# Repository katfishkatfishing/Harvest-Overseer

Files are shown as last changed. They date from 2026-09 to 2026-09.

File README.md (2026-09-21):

# Harvest-Overseer 🌱
>Built for third space Hack Club! - Week 1️⃣  
_It all started when two unemployed dudes stumbled upon a third, equally unemployed dude. Unburdened by 9-to-5s (erm but we have 9-5s for school) and fuelled by sheer ambition, the trio set off to blaze new trails, conquering land, sea, and hardware. Day and night they grind towards their goal — will they pull it off? Only fate can tell._

A stationary, comprehensive agricultural monitor that measures soil pH, moisture levels, nutrient concentrations (NPK), and light intensity. It displays the data of the plant and soil's health on an OLED screen to let you easily know what your plant needs.

## 💠 Project Overview 💠
**Harvest-Overseer** is an all-in-one agricultural monitor designed to take the guesswork out of plant care. Stationed directly in your garden bed or potted plant, it will continuously track essential environmental and soil parameters — displaying real-time health diagnostics on an integrated OLED screen so you always know exactly what your plants need to thrive.

### Key Features 🗝️
🥖**Soil pH & Nutrients Tracking:** Monitors pH balance and NPK (_Nitrogen, Phosphorus, Potassium_) concentrations.\
💧**Moisture Detection:** Measures active soil hydration levels to prevent over or under-watering.\
☀️**Light Intensity:** Tracks daily ambient light exposures to ensure optimal photosynthesis conditions.\
👁️**One-Glance Display:** Instant visual updates through a 7-pin SPI lcd.\
🔋**Battery Powered:** Fully portable design powered by a rechargeable Li-ion battery with integrated power management.  

## 🍰 PCB & Hardware Architecture 🥯
Harvest-Overseer uses a modular architecture consisting of a central **Master Unit (Main Brain)** for processing and display, and one or more remote **Sensor Node(s)** designed for low-power battery operation.
### Master Unit — The Core 🍎
The Master Unit receives sensor data, handles system logic, and drives the local OLED status display.
+ <ins>The BRAIN</ins>🧠 `ESP32-S3-WROOM-1-N16R8` to handle calculations, sensor input processing, and screen rendering.
+ <ins>The FACE</ins>🥶 14-pin socket (Conn_01x14_Socket) featuring dedicated connections for a `7-Pin SPI lcd` (_GND, VCC, CLK, MOSI, RES, DC, CS_)
+ <ins>The HEART</ins>🫀 An  integrated footprint of `TP4056充电源模块板` or `TP4056 charging power module board` for safe USB-C power delivery and Li-ion battery charging, and a `TPS7133Q` (a low dropout voltage regulator) that converts 4.2V to 3.3V for a clean and stable voltage rail for the ESP32-S3 and other sensitive logic pins.

_Master Unit PCB and Schematics_
<table>
  <tr>
    <td align="center">
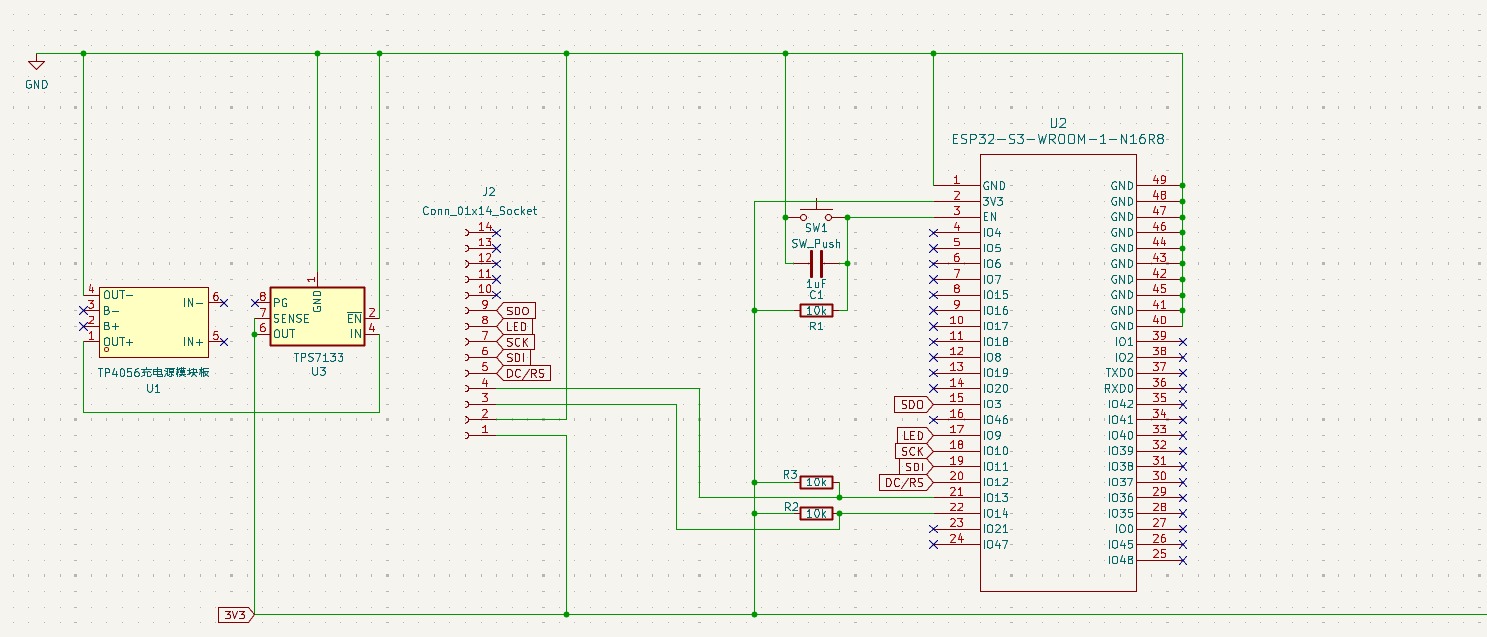
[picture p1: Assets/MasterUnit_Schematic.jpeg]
Master Unit Schematic
      <br>
      Schematic
    </td>
    <td align="center">
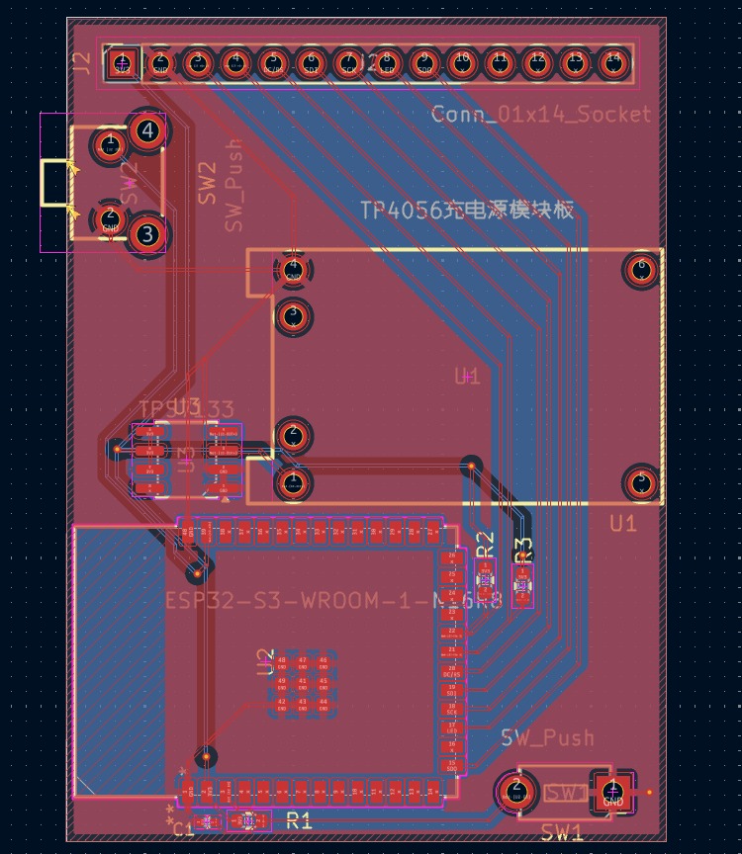
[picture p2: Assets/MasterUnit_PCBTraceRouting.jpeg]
Master Unit PCB Trace Routing
      <br>
      PCB Trace Routing
    </td>
  </tr>
  <tr>
    <td align="center">
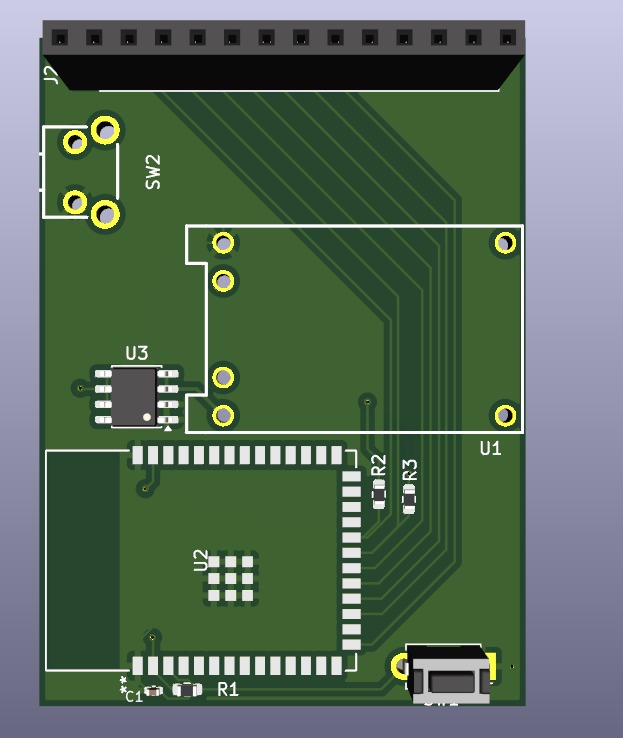
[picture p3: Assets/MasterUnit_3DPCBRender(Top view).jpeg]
Master Unit 3D PCB Render (Top view)
       <br>
      3D PCB Render (Top view)
    </td>
    <td align="center">
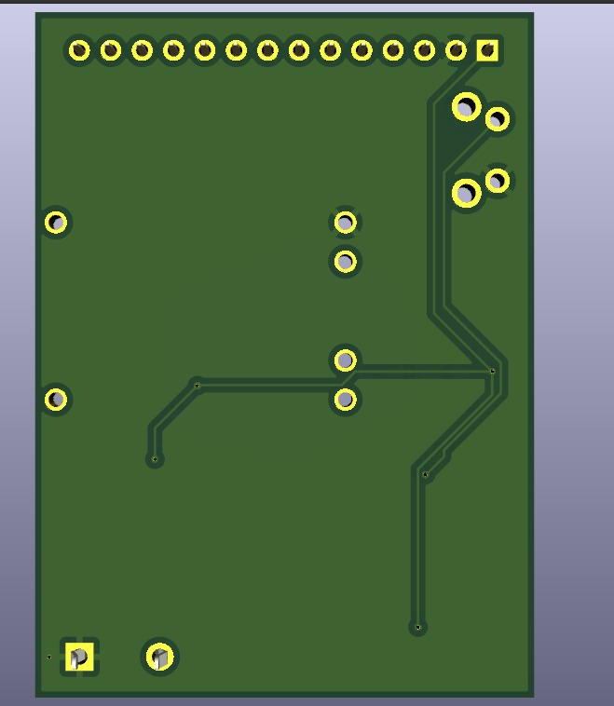
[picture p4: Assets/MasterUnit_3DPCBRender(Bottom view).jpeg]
Master Unit PCB Render (Bottom view)
      <br>
      3D PCB Render (Bottom view)
    </td>
  </tr>
</table>

### Sensor Node — The Backbone 🐙
The Sensor Node is an autonomous, ultra-low-power unit stationed in the soil bed to read the pH, moisture, light, and NPK levels, transmitting readings wirelessly back to the Core.

#### Components & Silicon 💎
+ <ins>The BRAIN_1</ins> `ESP32-C3-WROOM-02` (compact RISC-V Wi-Fi/BLE MCU) for reading sensors and beaming data to the Main Brain.
+ <ins>Power Management</ins> `MCP73871-2CC`, a LiPo/Li-ion charge manager with automatic power path management, allowing simultaneous solar/USB power supply and battery charging.
+ <ins>A Timer</ins>⏲️ `TPL5110`, a nano-power system timer that completely cuts off power to the entire node until a scheduled wake interval, drastically reducing standby drain to nano-amps for a long-term outdoor work.
+ <ins>Another High-Efficiency Power Management Component</ins>, the `DMG3415U` (P-Channel MOSFET) used to physically power down high-draw soil sensors when the node is sleeping.
+ <ins>Voltage Regulation (LDO)</ins> `HT7333` (Low quiescent current 3.3V regulator for logic and sensor rails).

#### Connectors & Peripherals 🖇️
+ <ins>USB-C Interface</ins>🔋 a `USB4085` GCT 16-pin USB-C receptacle for charging and power delivery.
+ <ins>Sensor Terminal Blocks</ins> `WAGO 233 Series` tool-less spring-cage terminals (2x08 and 2x04) for wiring of soil sensors (pH, NPK, moisture, light).
+ <ins>User Controls</ins>🫳 `B3U-1000P` tactile push button for manual settings, `LED_SMD_0603` status LED for charging state, `68k,10k,2k,100k,5.1k resistor smd 0603 & 470R resistor smd 0402` and `10uF capacitor smd 0402`for signal conditioning, and power rail decoupling.

<table>
  <tr>
    <td align="center">
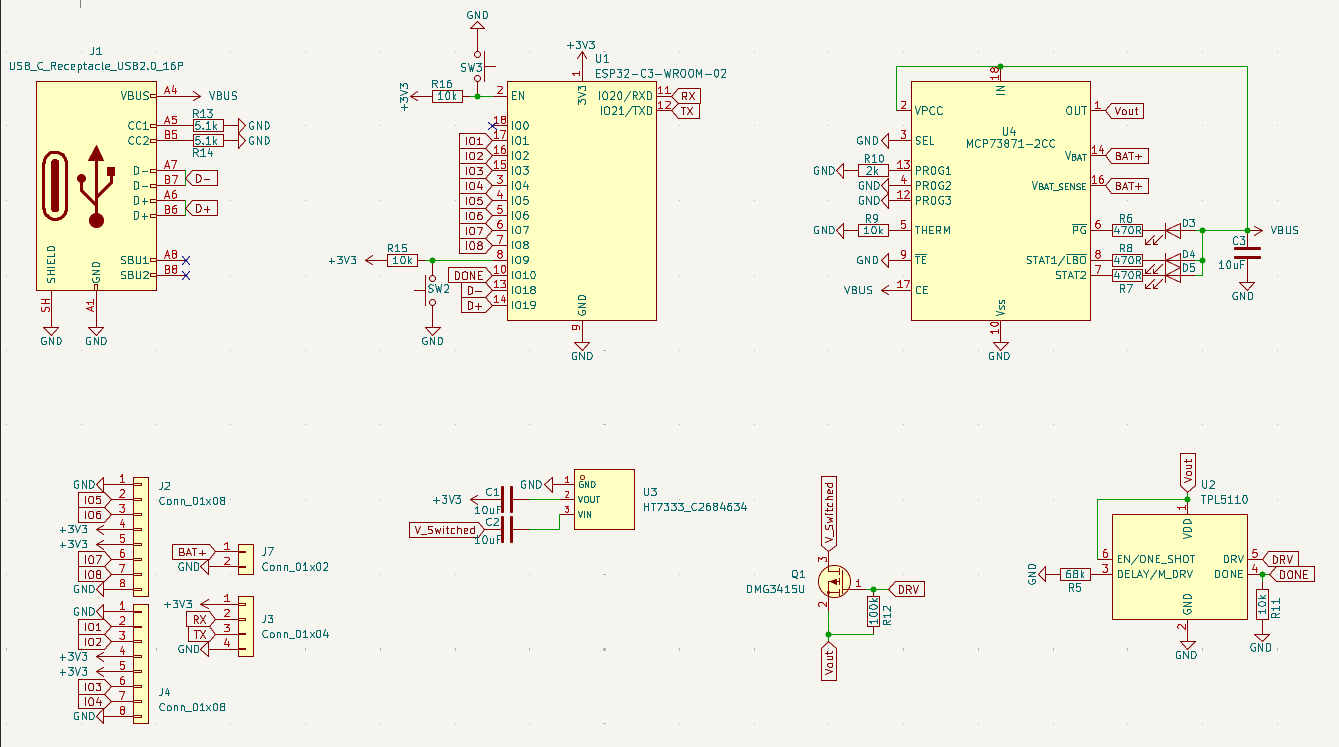
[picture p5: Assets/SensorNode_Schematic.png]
Sensor Node Schematic
      <br>
      Schematic
    </td>
  </tr>
</table>
<table>
  <tr>
    <td align="center">
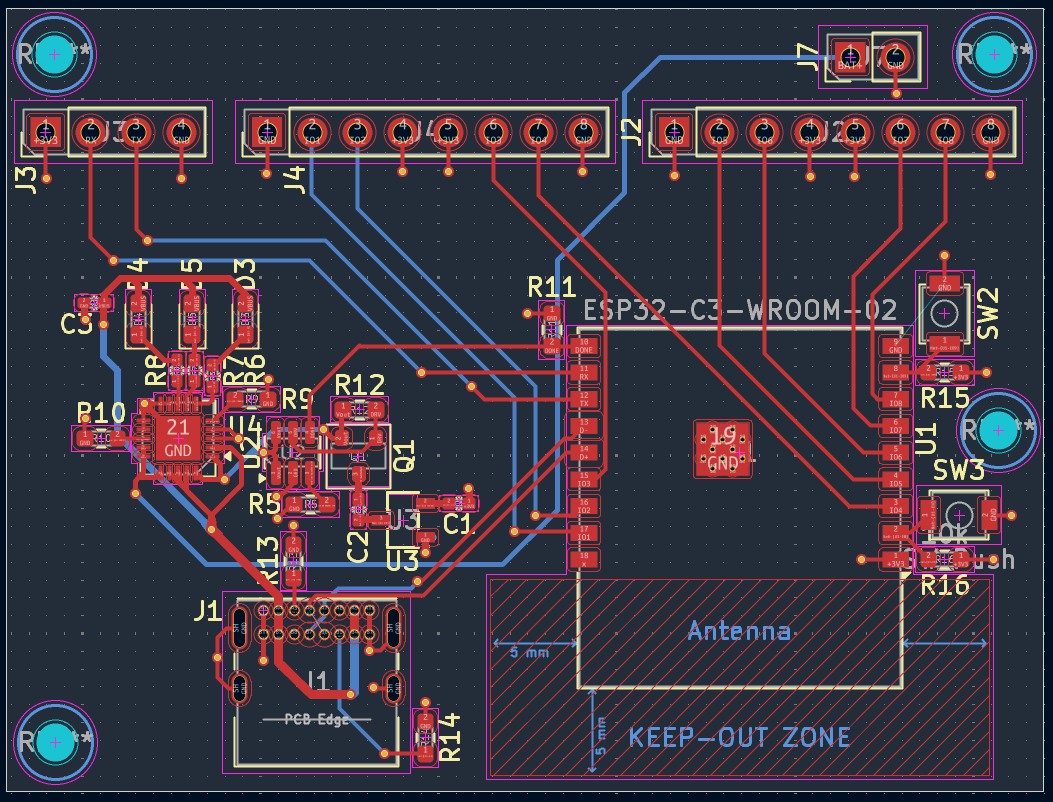
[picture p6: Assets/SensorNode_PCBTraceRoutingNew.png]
Sensor Node PCB Trace Routing
       <br>
      PCB Trace Routing
    </td>
    <td align="center">
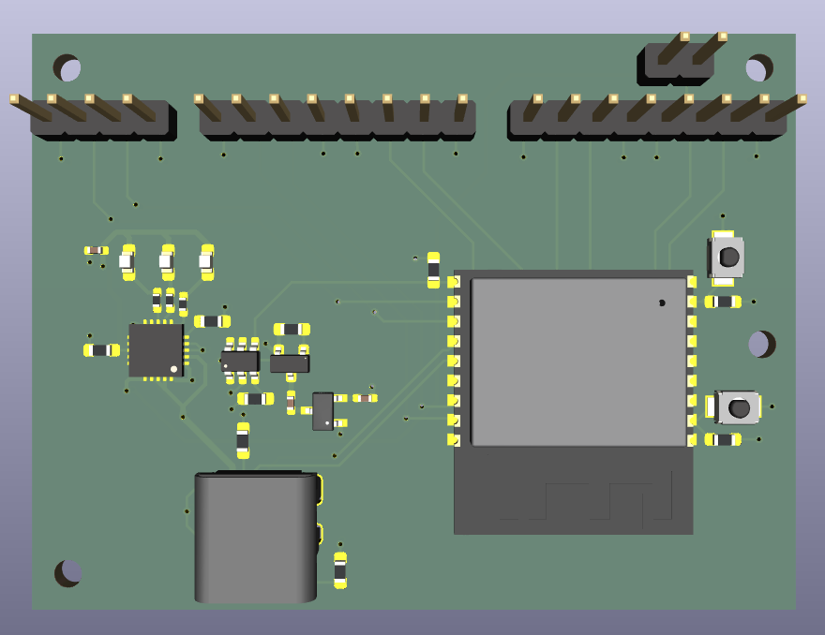
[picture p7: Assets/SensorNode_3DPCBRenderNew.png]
Sensor Node PCB Render
      <br>
      3D PCB Render
    </td>
  </tr>
</table>
<table>
  <tr>
    <td align="center">
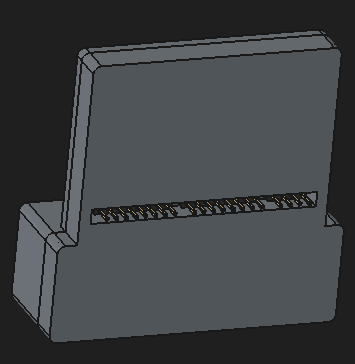
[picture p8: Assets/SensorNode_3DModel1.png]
Sensor Node 3D Model
       <br>
      3D Model
    </td>
    <td align="center">
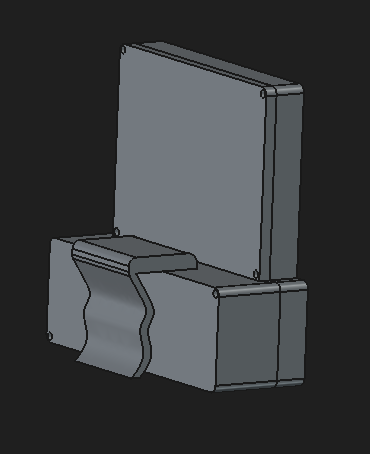
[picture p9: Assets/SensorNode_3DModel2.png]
Sensor Node PCB Render
      <br>
      3D Model
    </td>
  </tr>
</table>

## Display & User Interface 👾
`DLS24035B` for the display (3.5 Inch 480*320 SPI TFT LCD Module with ILI9488 Driver) with a custom case model.
<table>
  <tr>
    <td align="center">
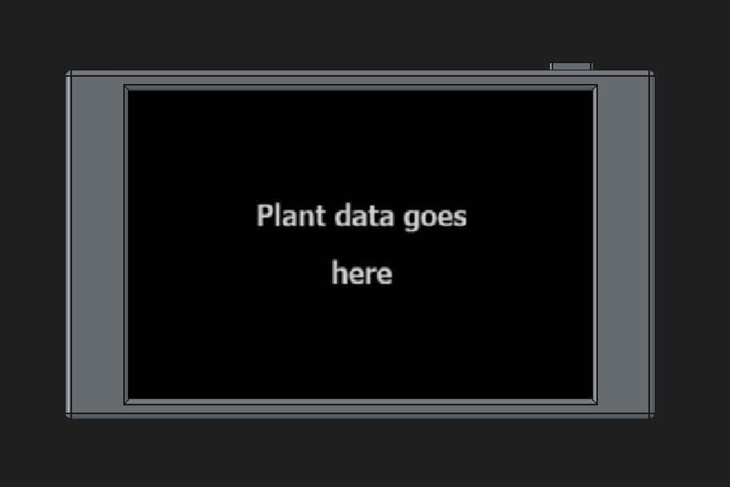
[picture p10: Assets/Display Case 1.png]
Angle 1
      <br>
      Front View
    </td>
    <td align="center">
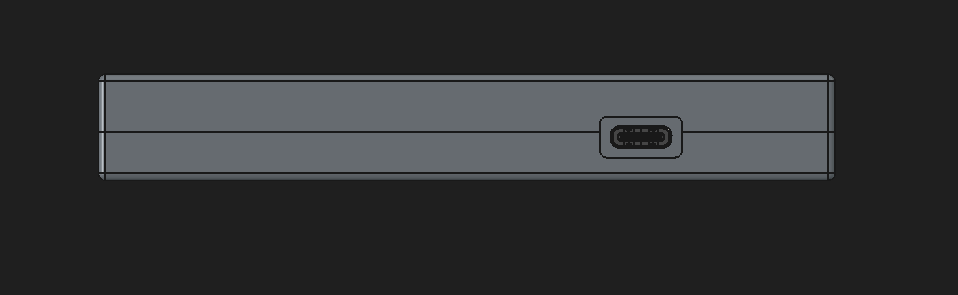
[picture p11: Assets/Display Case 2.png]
Angle 2
      <br>
      Bottom View
    </td>
  </tr>
</table>

_Here's a photo of the Master Unit PCB in the case._
<table>
  <tr>
    <td align="center">
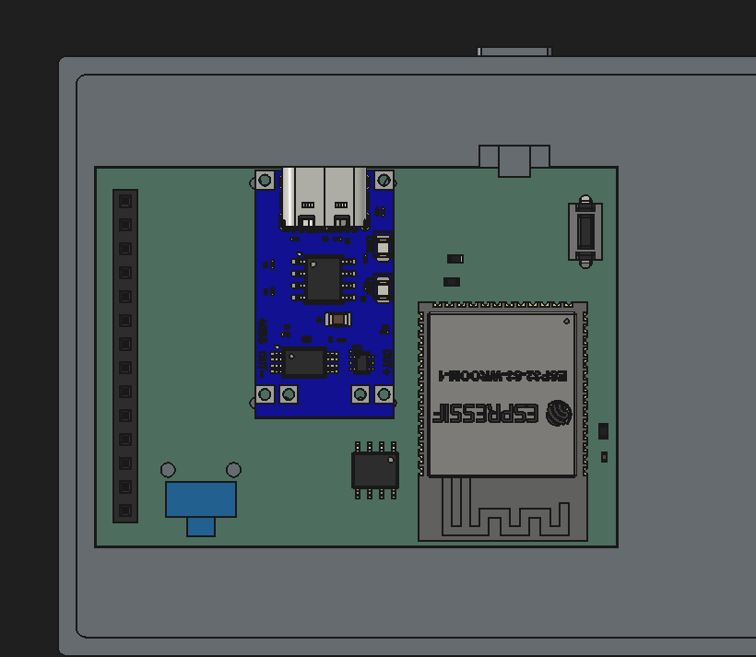
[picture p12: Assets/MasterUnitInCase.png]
3D PCB in case
      <br>
      Master Unit 3D PCB in case
    </td>
    <td align="center">
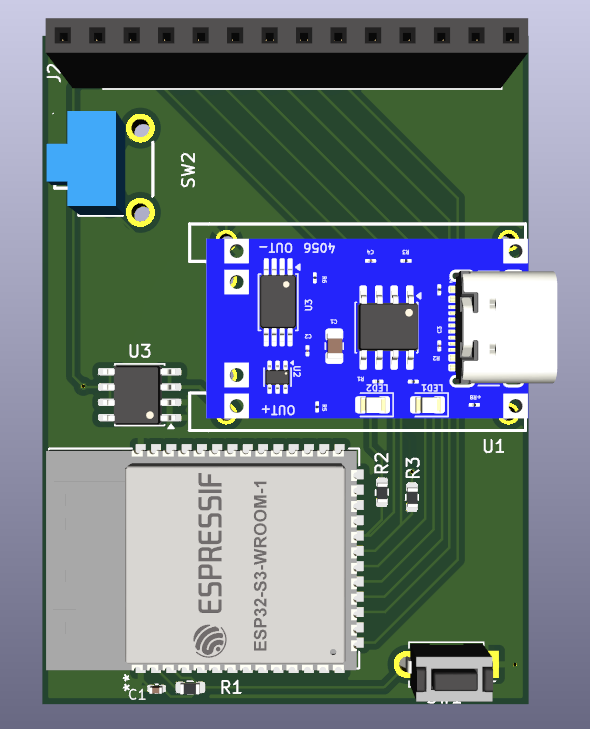
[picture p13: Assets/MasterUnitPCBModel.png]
3D PCB model
      <br>
      Master Unit 3D PCB model
    </td>
  </tr>
</table>

_Some display ui (done in the Figma software)_
<table>
  <tr>
    <td align="center">
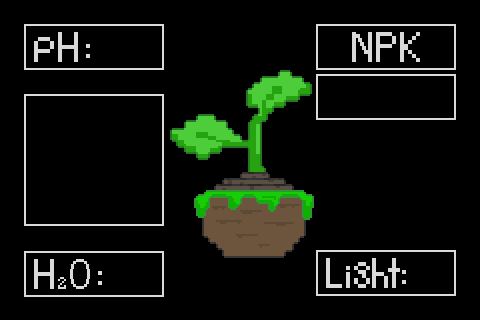
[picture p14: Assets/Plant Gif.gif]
Plant is helth
      <br>
      Plant in good helth
    </td>
    <td align="center">
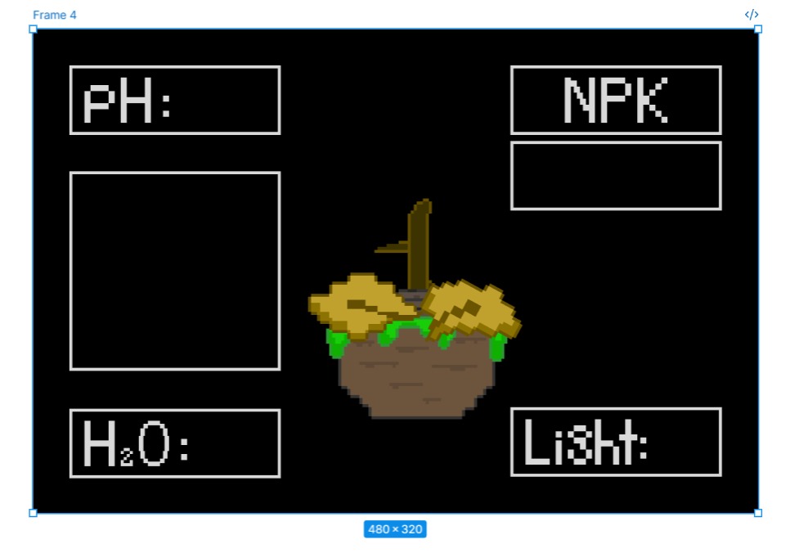
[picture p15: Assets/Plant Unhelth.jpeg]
Plant is unhelth
      <br>
      Plant is unhelth
    </td>
  </tr>
</table>

## Components Used
+ ESP32-S3-WROOM-1-N16N
+ 14-pin socket (Conn_01x14_Socket)
+ TP4056 charging power module board
+ TPS7133Q LDO
+ ESP32-C3-WROOM-02
+ MCP73871-2CC
+ TPL5110
+ DMG3415U
+ HT7333_C2684634
+ USB-C receptacle GCT_USB4085
+ Terminal block WAGO_233-508_2x08
+ Terminal block WAGO_233-508_2x04
+ Button switch SW_SPST_B3U-1000P
+ LED_SMD_0603
+ 10µF capacitor SMD 0402
+ 68k, 10k, 2k, 100k, 5.1k resistor SMD 0603
+ 470R resistor SMD 0402
+ DLS24035B (3.5inch 480*320 SPI TFT LCD Module with ILI9488 Driver)

## BOM
| MCU | ESP32-C3-WROOM-02 | 1 | 1.80  | 1.80  | https://www.aliexpress.com/item/1005003181553659.html |
| --- | --- | --- | ----- | ----- | --- |
| 2.54mm Female Header | Conn_01x08_Socket | 2 | 0.15  | 0.75  | https://www.aliexpress.com/w/wholesale-2.54mm-female-header.html |
| 2.54mm Female Header | Conn_01x04_Socket | 1 | 0.10  | 0.50  | https://www.aliexpress.com/w/wholesale-2.54mm-female-header.html |
| 2.54mm Female Header | Conn_01x02_Socket | 1 | 0.08  | 0.40  | https://www.aliexpress.com/w/wholesale-2.54mm-female-header.html |
| LiPo/Li-ion Battery Management IC | MCP73871-2CC | 1 | 2.20  | 2.20  | https://www.aliexpress.com/item/1005009931582723.html |
| Ultra-Low-Power Timer | TPL5110 | 1 | 3.50  | 3.50  | https://www.aliexpress.com/item/1005009324980307.html |
| P-Channel MOSFET | DMG3415U | 1 | 0.09  | 8.50  | https://www.aliexpress.com/item/1005009968198030.html |
| Low-Power LDO | HT7333_C2684634 | 1 | 0.10  | 1.00  | https://www.aliexpress.com/item/32697055615.html |
| USB-C Receptacle | GCT_USB4085 | 1 | 0.35  | 1.75  | https://www.aliexpress.com/w/wholesale-16p-usb-c-receptacle.html |
| Terminal block | WAGO_233-508_2x08 | 1 | 1.20  | 1.20  | https://www.aliexpress.com/w/wholesale-wago-233.html |
| Terminal block | WAGO_233-508_2x04 | 1 | 0.70  | 0.70  | https://www.aliexpress.com/w/wholesale-wago-233.html |
| Button switch | SW_SPST_B3U-1000P | 2 | 0.10  | 1.00  | https://www.aliexpress.com/w/wholesale-smd-tactile-switch.html |
| LED | SMD_0603 | 3 | 0.01  | 0.80  | https://www.aliexpress.com/w/wholesale-0603-smd-led.html |
| Ceramic Capacitor SMD | 10µF 0402 | 3 | 0.01  | 0.90  | https://www.aliexpress.com/w/wholesale-0402-10uf.html |
| Ceramic Resistor SMD | 68k 0603 | 1 | 0.01  | 0.50  | https://www.aliexpress.com/w/wholesale-smd-resistor-sample-book.html |
| Ceramic Resistor SMD | 10k 0603 | 4 | 0.01  | 0.50  | https://www.aliexpress.com/w/wholesale-smd-resistor-sample-book.html |
| Ceramic Resistor SMD | 2k 0603 | 1 | 0.01  | 0.50  | https://www.aliexpress.com/w/wholesale-smd-resistor-sample-book.html |
| Ceramic Resistor SMD | 100k 0603 | 1 | 0.01  | 0.50  | https://www.aliexpress.com/w/wholesale-smd-resistor-sample-book.html |
| Ceramic Resistor SMD | 5.1k 0603 | 2 | 0.01  | 0.50  | https://www.aliexpress.com/w/wholesale-smd-resistor-sample-book.html |
| Ceramic Resistor SMD | 470R 0402 | 3 | 0.01  | 0.50  | https://www.aliexpress.com/w/wholesale-smd-resistor-sample-book.html |
| Liquid Crystal Display | DLS24035B | 1 | 9.20  | 9.20  | https://www.aliexpress.com/item/1005005287088814.html |
| Capacitor SMD | 1uF 0603 (C_0402_1005Metric) | 1 | 2.27  | 2.27  | https://www.aliexpress.com/item/1005012364450156.html |
| 2.54mm Female Header | Conn_01x14_Socket (PinSocket_1x14_P2.54mm_Vertical) | 1 | 2.89  | 2.89  | https://www.aliexpress.com/item/1005003610333849.html |
| Resistor SMD | 10k 0603 (R_0603_1608Metric) | 3 | 0.45  | 1.36  | https://www.aliexpress.com/item/1005005677654015.html |
| Push Button Switch (THT) | MJTP1243 (SW_PUSH_1P1T_6x3.5mm_H4.3_APEM_MJTP1243)  | 1 | 0.42  | 0.42  | https://www.digikey.com/en/products/detail/apem-inc/MJTP1243/1798039 |
| Side Tactile Switch (SMD) | TS-1101-C-W (SW-SMD_TC-1101V-C-B-W) | 1 | 0.40  | 0.40  | https://item.szlcsc.com/300030.html |
| Power Module | TP4056 module (PWRM-TH_TP4056) | 1 | 1.73  | 1.73  | https://www.aliexpress.com/item/1005005982385924.html |
| MCU Module | ESP32-S3-WROOM-1-N16R8 (ESP32-S3-WROOM-1_EXP) | 1 | 4.78  | 4.78  | https://www.aliexpress.com/item/1005005230800143.html |
| Voltage Regulator IC | TPS7133 (SOIC-8_3.9x4.9mm_P1.27mm) | 1 | 15.36 | 15.36 | https://www.aliexpress.com/item/1005012324115212.html |

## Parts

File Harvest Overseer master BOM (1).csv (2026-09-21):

Qty | Value | Footprint | Price per lot (usd) | Source
1 | 1uF 0603 | Capacitor_SMD:C_0402_1005Metric | 2.27 | https://www.aliexpress.com/item/1005012364450156.html
1 | Conn_01x14_Socket | Connector_PinSocket_2.54mm:PinSocket_1x14_P2.54mm_Vertical | 2.89 | https://www.aliexpress.com/item/1005003610333849.html?scm_id=1007.40050.354490.0&scm-url=1007.40050.354490.0
3 | 10k 0603 | Resistor_SMD:R_0603_1608Metric | 1.36 | https://www.aliexpress.com/item/1005005677654015.html
1 | MJTP1243 | Button_Switch_THT:SW_PUSH_1P1T_6x3.5mm_H4.3_APEM_MJTP1243 | 0.42 | https://www.digikey.com/en/products/detail/apem-inc/MJTP1243/1798039
1 | TS-1101-C-W | sidebutton:SW-SMD_TC-1101V-C-B-W | 0.40 | https://item.szlcsc.com/300030.html
1 | TP4056 module | easyeda2kicad:PWRM-TH_TP4056 | 1.73 | https://www.aliexpress.com/item/1005005982385924.html
1 | ESP32-S3-WROOM-1-N16R8 | esp32 somethingsomethingsomething:ESP32-S3-WROOM-1_EXP | 4.78 | https://www.aliexpress.com/item/1005005230800143.html
1 | TPS7133 | Package_SO:SOIC-8_3.9x4.9mm_P1.27mm | 15.36 | https://www.aliexpress.com/item/1005012324115212.html

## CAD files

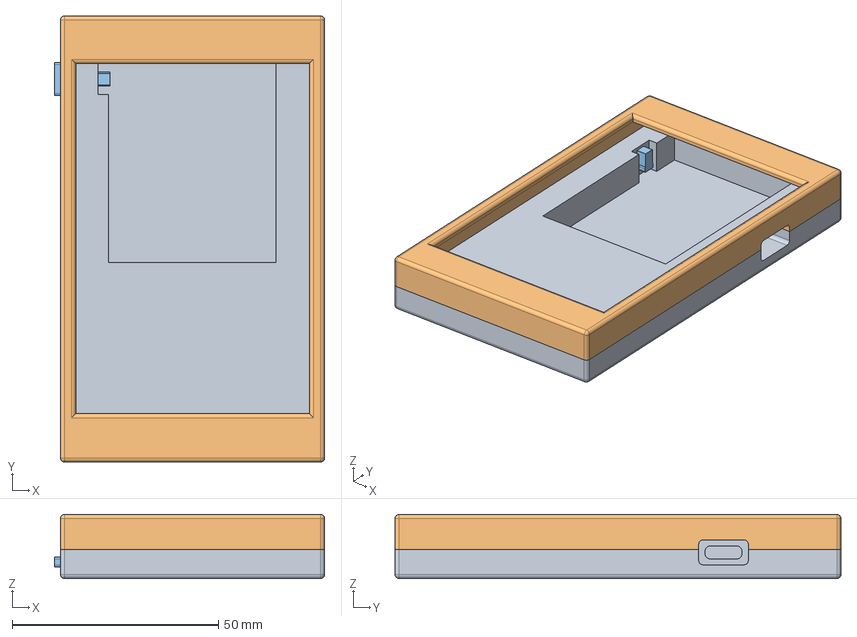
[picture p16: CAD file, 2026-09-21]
Master 3D Case/harvestoverseermaster-case.step
65.5 x 108.0 x 15.5 mm
ButtonCap

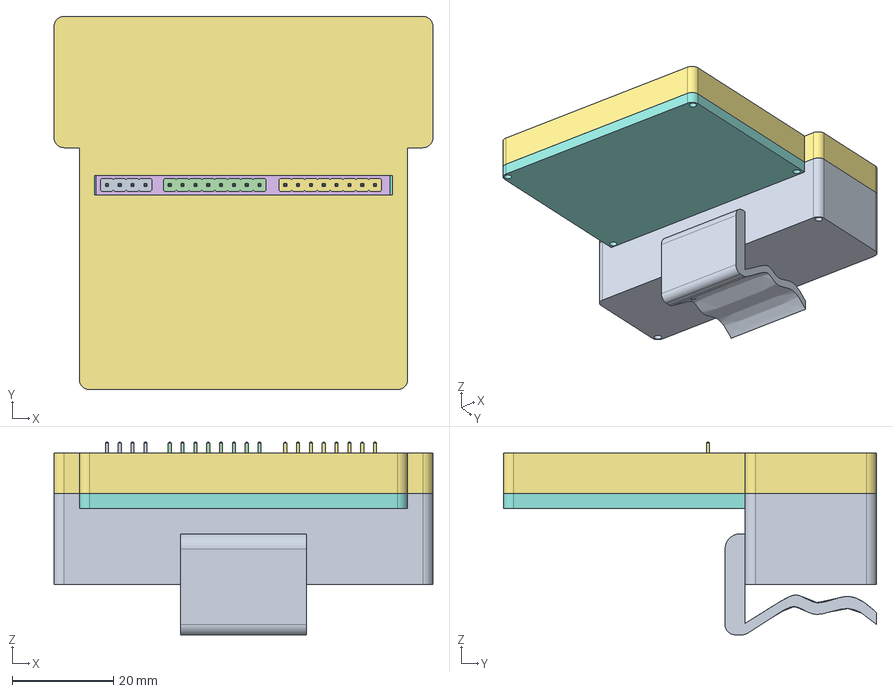
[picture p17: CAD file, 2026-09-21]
SensorNode 3D Case Model/Harvest Overseer Node.FCStd
75.0 x 73.9 x 38.1 mm
PinHeader_1x04_P254mm_Vertical
R_0603_1608Metric
R_0402_1005Metric
PinHeader_1x08_P254mm_Vertical
R_0603_1608Metric002
SW_SPST_B3U-1000P
SOT-23
SW_SPST_B3U-1000P002
QFN-20-1EP_4x4mm_Pitch0.5mm
C_0402_1005Metric
C_0402_1005Metric002
LED_0603_1608Metric
SOT-23-6
R_0603_1608Metric004
PinHeader_1x08_P254mm_Vertical001
R_0603_1608Metric006
R_0402_1005Metric002
R_0603_1608Metric008
SOT-23-3L_L2.9-W1.6-H1.1-LS2.8-P0.95
ESP32-C3-WROOM-02
C_0402_1005Metric004
R_0603_1608Metric010
R_0603_1608Metric012
LED_0603_1608Metric002
R_0603_1608Metric014
R_0603_1608Metric016
USB_C_Receptacle_GCT_USB4085
LED_0603_1608Metric004
R_0402_1005Metric004
YieldSmart_PCB
Top_Case
Bottom_Case_EE
Bottom_Case_Battery

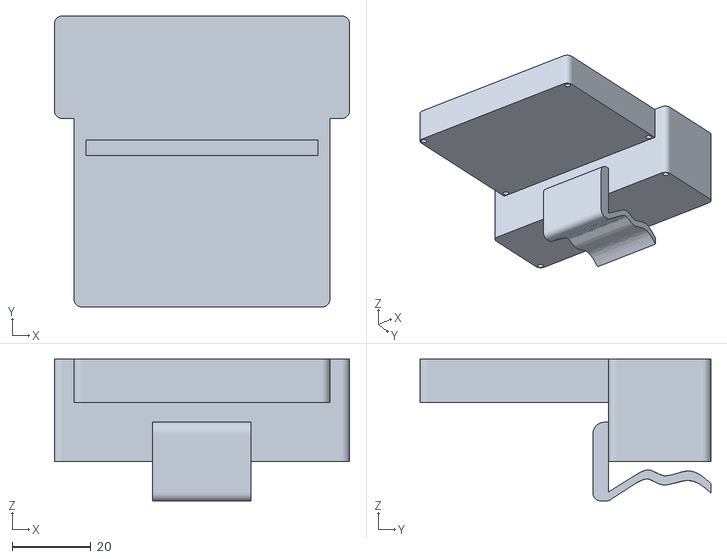
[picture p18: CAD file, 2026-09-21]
SensorNode 3D Case Model/Harvest Overseer Node-Part.stl
75.0 x 73.9 x 36.0

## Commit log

2026-09-18 Fix display type in README features section
    Corrected the display type in the features section from 'SPI OLED screen' to '7 pin spi lcd'.
2026-09-18 Fix formatting in PCB & Hardware Architecture section
    Updated hardware architecture section with proper formatting.
2026-09-18 Revise PCB & Hardware Architecture details
    Updated PCB and hardware architecture section with detailed descriptions of components.
2026-09-18 Revise PCB & Hardware Architecture section header
    Updated section header and improved formatting for clarity.
2026-09-20 I lied
    [YieldSmart-B_Cu.gbr, YieldSmart-B_Mask.gbr, YieldSmart-B_Paste.gbr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]
2026-10-31 Update Harvest Overseer master BOM (1).csv
2026-10-31 Rename Harvest Overseer master BOM (1).csv to BOM_Master.csv
2026-10-31 Update and rename BOM.csv to BOM_Node.csv
2026-11-10 updated journal
    Added sections for Sensor Node and Master Node with detailed lapses and images.
2026-11-10 add kicad files
2026-11-10 Added kicad file for node
